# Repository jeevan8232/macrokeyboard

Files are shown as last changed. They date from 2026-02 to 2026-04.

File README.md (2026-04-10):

# macrokeyboard
macro keyboard and space mouse using rpi pico. circuitpython code

https://www.thingiverse.com/thing:7293580

https://www.youtube.com/watch?v=AjmmTDKetks

# Hand-Wiring the Electronics

Since we are keeping this accessible, there is no custom PCB required—everything is hand-wired directly to the microcontroller!

Hand-wiring a project like this is incredibly rewarding. Take your time, trim your wires to length so they fit nicely inside the shell, and double-check your connections as you go.

Below is the complete wiring guide based on the Raspberry Pi Pico (RP2040) pinout used for this project.

1. Power Distribution (ALL components VCC (+) and GND (-))
First, let's establish our power and ground lines. It helps to daisy-chain your ground wires or create a small ground hub.

VBUS (Pin 40, 5V from USB): Connect your LED Strip VCC here.
3V3 (Pin 36, 3.3V Out): Connect the Joystick VCC, Magnetometer VCC, and Rotary Encoder VCCs here.
GND (Any Ground Pin): Connect the GND from all components (LEDs, Joystick, Magnetometer, Encoders, Extra Switches, etc.) to the microcontroller's ground.
2. The Key Matrix (Macro Keyboard)
To save pins, the mechanical switches are wired in a 5x5 matrix. You will need to solder diodes to your switches to prevent "ghosting" when pressing multiple keys.

🚨 CRITICAL DIODE NOTE: When soldering the 1N4148 diodes to the mechanical switches, the black line on the diode must face AWAY from the switch pin, Check the image.

* Rows (Solder to the diode tails):

Row 1 ➔ GP0
Row 2 ➔ GP1
Row 3 ➔ GP2
Row 4 ➔ GP3
Row 5 ➔ GP4
Columns (Solder to the other switch pin): (Note: These are wired in reverse order in the code! Don't worry we can always change the pin numbers in the code)
Col 1 ➔ GP9
Col 2 ➔ GP8
Col 3 ➔ GP7
Col 4 ➔ GP6
Col 5 ➔ GP5
3. The Space Mouse (Magnetometer & Joystick)
This is the core of our 3D navigation!

Magnetometer (MLX90393): This communicates via I2C. Ensure your breakout board is in I2C mode.
SDA ➔ GP16
SCL ➔ GP17

Analog Joystick Module:
VRx (X-Axis) ➔ GP27
VRy (Y-Axis) ➔ GP26
SW (Button) ➔ GP22

4. Rotary Encoders & Extra Buttons
These give you scroll and quick-action control.

Encoder 1 (Left - Horizontal Scroll / Right Click):
CLK ➔ GP10
DT ➔ GP11
SW ➔ GP12
Encoder 2 (Right - Vertical Scroll / Home):
CLK ➔ GP13
DT ➔ GP14
SW ➔ GP15
Extra Button 1 (F6 - Fit View): Wire one leg to GP18, the other to GND.
Extra Button 2 (Mode/Color Cycle): Wire one leg to GP19, the other to GND.
5. RGB Lighting
To give the macro pad that premium glow:

WS2812B Data In (DIN): ➔ GP28

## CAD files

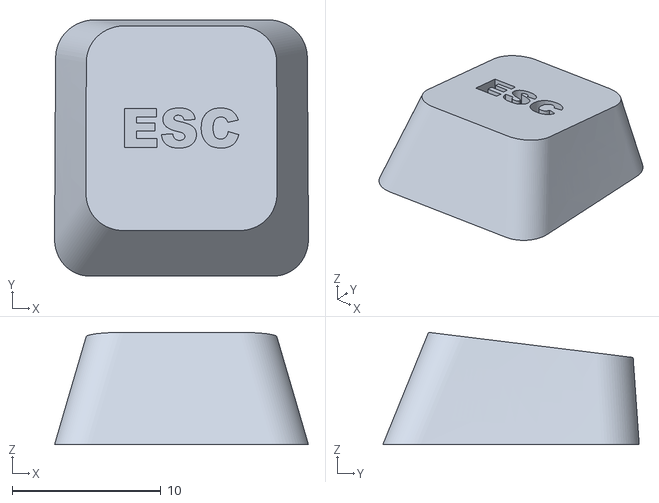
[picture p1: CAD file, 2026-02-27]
3d files/stl/MX Keycap check tolerance by printing one upside down no support /MX Keycap ESC.stl
17.1 x 17.2 x 7.55

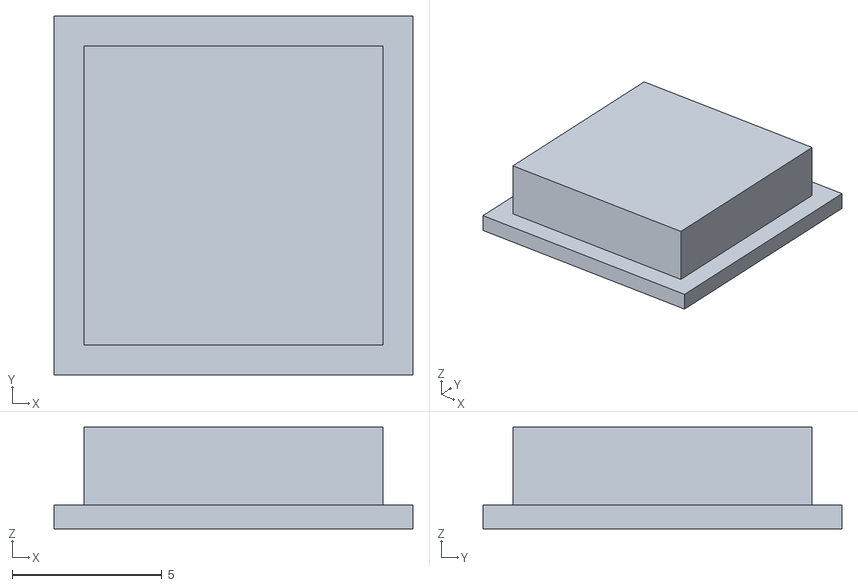
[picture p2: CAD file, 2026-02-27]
3d files/stl/switch x 2 copies.stl
12.0 x 12.0 x 3.40

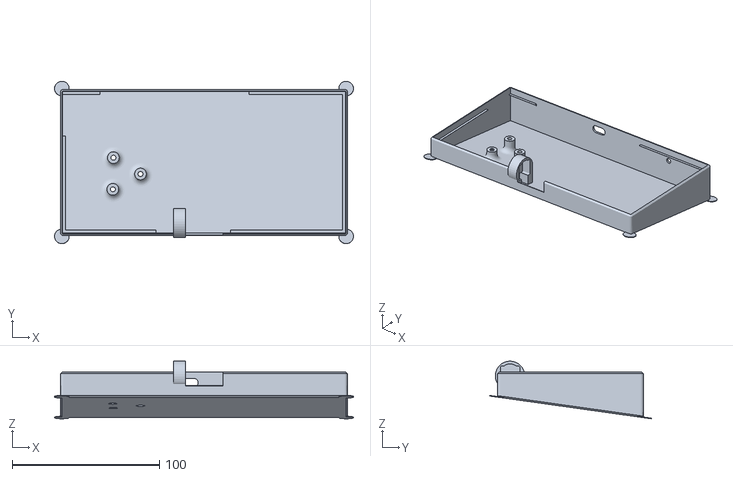
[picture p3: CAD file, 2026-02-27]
3d files/stl/Base with support tree.stl
203.0 x 110.3 x 39.1

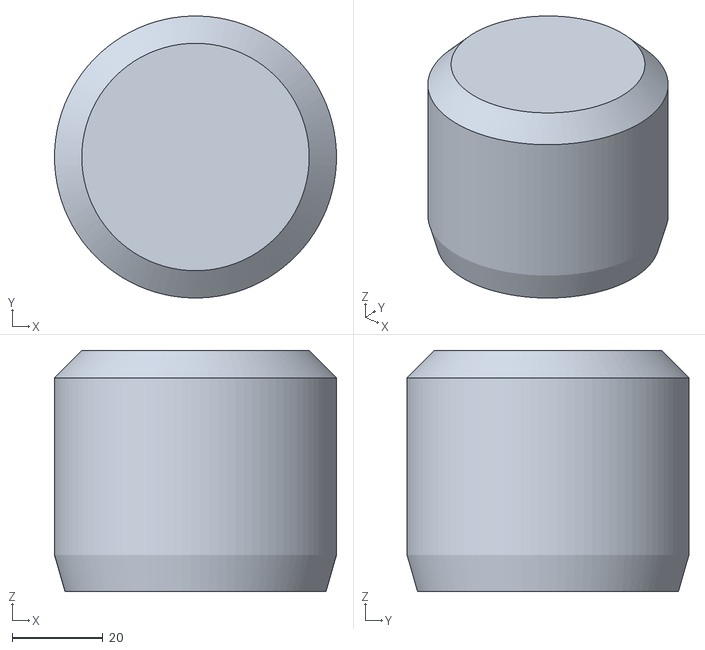
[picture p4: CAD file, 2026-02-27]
3d files/stl/Spacemouse Knob.stl
62.0 x 62.0 x 53.0

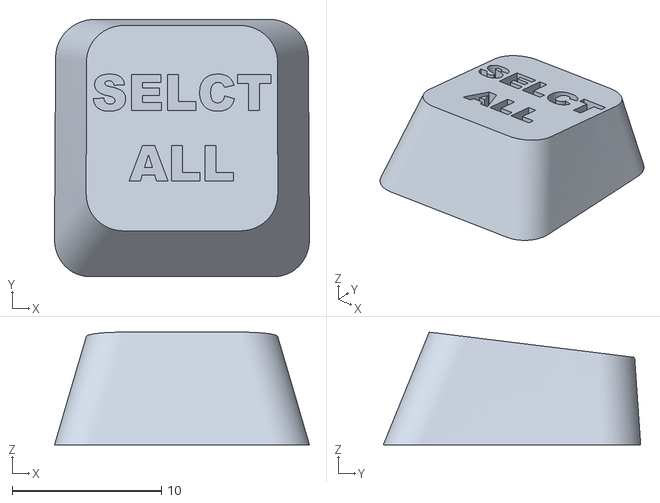
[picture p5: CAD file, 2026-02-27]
3d files/stl/MX Keycap check tolerance by printing one upside down no support /MX Keycap Select All.stl
17.1 x 17.2 x 7.55

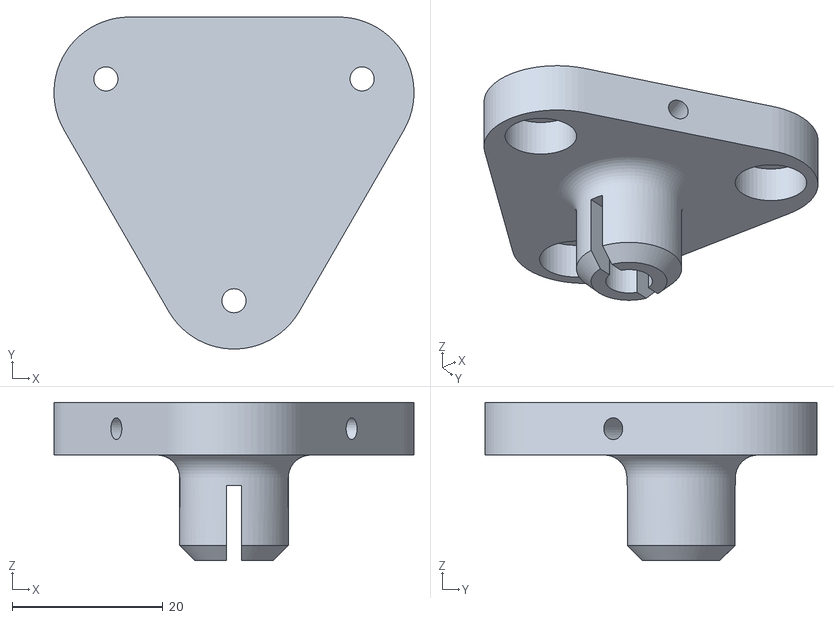
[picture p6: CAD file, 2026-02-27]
3d files/stl/Spacemouse Top Magnet Holder.stl
47.7 x 44.0 x 21.0

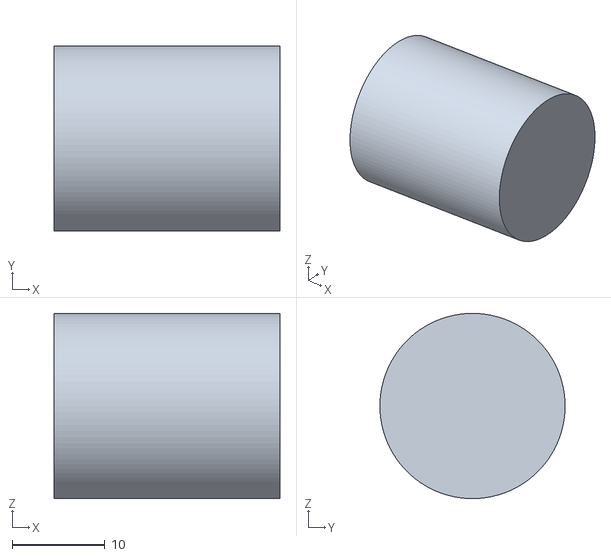
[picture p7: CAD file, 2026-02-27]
3d files/stl/Encoder knob vertical scroll.stl
24.4 x 20.0 x 20.0

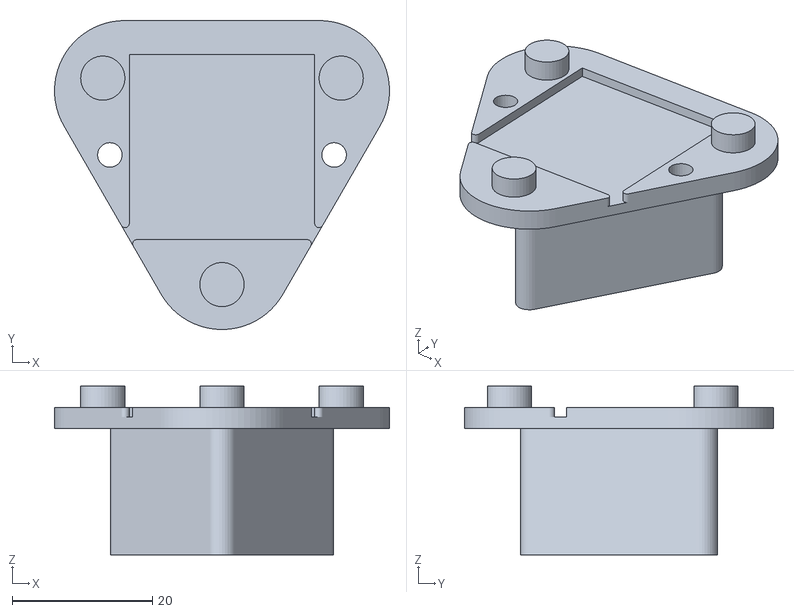
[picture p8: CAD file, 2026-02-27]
3d files/stl/Spacemouse base.stl
47.7 x 44.0 x 24.0

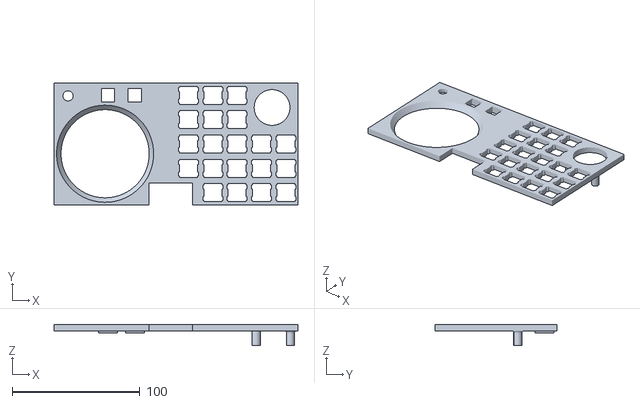
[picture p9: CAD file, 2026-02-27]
3d files/stl/Top.stl
191.0 x 95.2 x 16.6

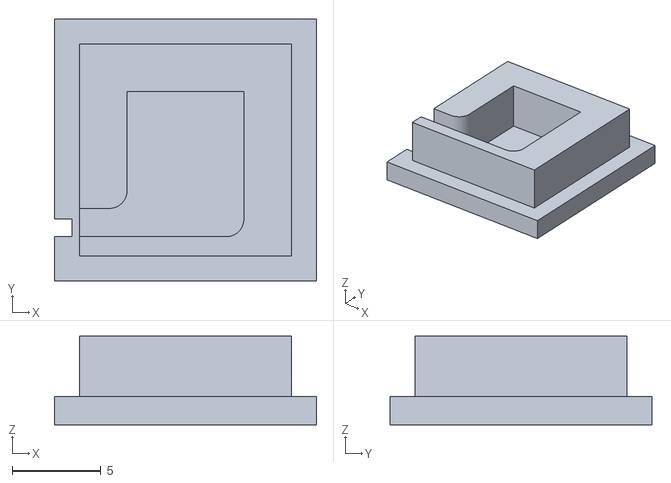
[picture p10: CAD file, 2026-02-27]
3d files/stl/switch base x 2 copies.stl
14.8 x 14.8 x 5.00

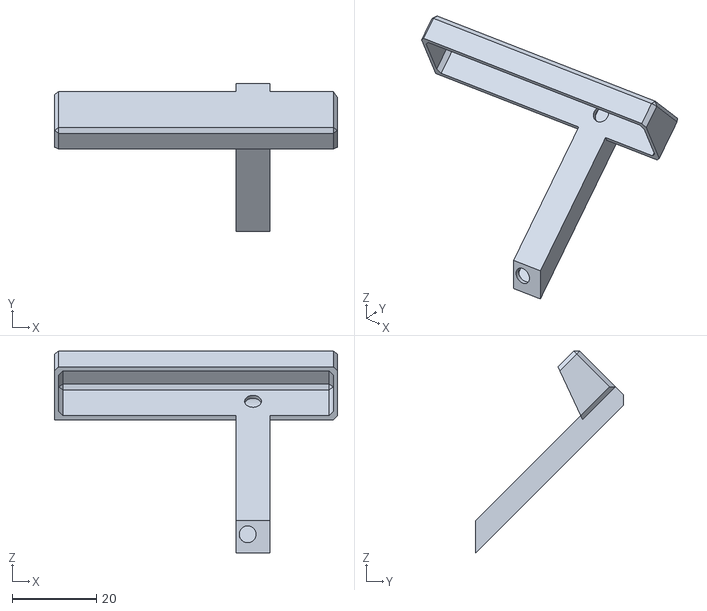
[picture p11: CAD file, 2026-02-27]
3d files/stl/Ledstrip case.stl
67.0 x 34.9 x 47.8

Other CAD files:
3d files/stl/MX Keycap check tolerance by printing one upside down no support /MX Keycap Find.stl
3d files/stl/MX Keycap check tolerance by printing one upside down no support /MX Keycap Paste.stl
3d files/stl/MX Keycap check tolerance by printing one upside down no support /MX Keycap Home.stl
3d files/stl/MX Keycap check tolerance by printing one upside down no support /MX Keycap Extrude.stl
3d files/stl/MX Keycap check tolerance by printing one upside down no support /Arrow Up.stl
3d files/stl/MX Keycap check tolerance by printing one upside down no support /Arrow Down.stl
3d files/stl/MX Keycap check tolerance by printing one upside down no support /MX Keycap Switch Window.stl
3d files/stl/Encoder knob horizontal scroll.stl
3d files/stl/Ledstrip cover.stl
3d files/stl/MX Keycap check tolerance by printing one upside down no support /Arrow Left.stl
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

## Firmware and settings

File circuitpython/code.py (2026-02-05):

import time
import board
import digitalio
import usb_hid
import rotaryio
import keypad
import analogio
import neopixel
import busio
from adafruit_hid.keyboard import Keyboard
from adafruit_hid.keycode import Keycode
from adafruit_hid.consumer_control import ConsumerControl
from adafruit_hid.consumer_control_code import ConsumerControlCode
from adafruit_hid.mouse import Mouse

# --- 1. CONFIGURATION ---

COMMAND = Keycode.GUI 

# Key Matrix Pins
ROW_PINS = (board.GP0, board.GP1, board.GP2, board.GP3, board.GP4)
COL_PINS = (board.GP9, board.GP8, board.GP7, board.GP6, board.GP5)

# Encoder Pins
ENC1_CLK, ENC1_DT, ENC1_SW = board.GP10, board.GP11, board.GP12
ENC2_CLK, ENC2_DT, ENC2_SW = board.GP13, board.GP14, board.GP15

# Joystick & Extra Buttons
JOY_X_PIN = board.GP27
JOY_Y_PIN = board.GP26
JOY_SW_PIN = board.GP22
BTN_EXTRA1_PIN = board.GP18
BTN_EXTRA2_PIN = board.GP19

# I2C (Space Mouse) & LED
I2C_SDA, I2C_SCL = board.GP16, board.GP17
LED_PIN = board.GP28
NUM_LEDS = 4

# SCROLL SETTINGS
SCROLL_SPEED = 20  # Set to 1 for default, 2 or 3 for faster scrolling

# LED COLOR CYCLE SETTINGS
# 4 Colors + OFF at the end
LED_COLORS = [
    (255, 100, 0),   # 1. Cyan
    (0, 0, 255),   # 2. Magenta
    (255, 255, 0),   # 3. Yellow
    (255, 255, 255), # 4. White
    (0, 0, 0)        # 5. OFF
]

# SPACE MOUSE SETTINGS (Fusion 360)
SM_DEADZONE = 100.0      
SM_SENSITIVITY = 15.0   
SM_Z_THRESHOLD = 100.0   

# --- 2. SETUP OBJECTS ---

kbd = Keyboard(usb_hid.devices)
cc = ConsumerControl(usb_hid.devices)
mouse = Mouse(usb_hid.devices)

# LED Setup
pixels = neopixel.NeoPixel(LED_PIN, NUM_LEDS, brightness=1.0)
pixels.fill((255, 255, 0)) # Startup Orange (Not in cycle, just for boot)

# Matrix Setup
keys = keypad.KeyMatrix(ROW_PINS, COL_PINS, columns_to_anodes=True)

# Direct Keys
# Index 0: Extra1, Index 1: Extra2, Index 2: Joystick Btn
direct_keys = keypad.Keys(
    (BTN_EXTRA1_PIN, BTN_EXTRA2_PIN, JOY_SW_PIN),
    value_when_pressed=False,
    pull=True
)

# Encoders
encoder1 = rotaryio.IncrementalEncoder(ENC1_CLK, ENC1_DT)
last_position1 = 0
encoder2 = rotaryio.IncrementalEncoder(ENC2_CLK, ENC2_DT)
last_position2 = 0

# Encoder Switches
encoder_switches = keypad.Keys(
    (ENC1_SW, ENC2_SW),
    value_when_pressed=False,
    pull=True
)

# Joystick Analog
joy_x = analogio.AnalogIn(JOY_X_PIN)
joy_y = analogio.AnalogIn(JOY_Y_PIN)

# Magnetometer Setup & Calibration
mlx = None
mlx_offsets = [0, 0, 0] 

try:
    import adafruit_mlx90393
    i2c = busio.I2C(I2C_SCL, I2C_SDA, frequency=400_000)
    mlx = adafruit_mlx90393.MLX90393(i2c)
    mlx.gain = adafruit_mlx90393.GAIN_1X 
    print("MLX90393 Found! Calibrating...")
    
    # Calibration Routine
    x_sum, y_sum, z_sum = 0, 0, 0
    for _ in range(20):
        mx, my, mz = mlx.magnetic
        x_sum += mx
        y_sum += my
        z_sum += mz
        time.sleep(0.01)
    
    mlx_offsets = [x_sum/20, y_sum/20, z_sum/20]
    print("Calibration Done:", mlx_offsets)
    pixels.fill((0, 255, 0)) # Green = Ready
    time.sleep(0.2)
    pixels.fill(LED_COLORS[0]) # Set to first color in cycle

except Exception as e:
    print("MLX90393 Init Failed:", e)
    pixels.fill((255, 0, 0)) # Red = Error

# --- 3. KEY MAPPING ---

KEYMAP = [
    [(COMMAND, Keycode.C), (COMMAND, Keycode.V), (COMMAND, Keycode.A), None, None],
    [(COMMAND, Keycode.ALT, Keycode.V), (COMMAND, Keycode.F), Keycode.ESCAPE, None, None],
    [Keycode.HOME, Keycode.E, (COMMAND, Keycode.Z), Keycode.SPACEBAR, Keycode.L],
    [Keycode.SHIFT, Keycode.COMMAND, Keycode.UP_ARROW, Keycode.TAB, Keycode.RIGHT_CONTROL],
    [None, Keycode.LEFT_ARROW, Keycode.DOWN_ARROW, Keycode.RIGHT_ARROW, (COMMAND, Keycode.S)]
]

# --- 4. HELPER FUNCTIONS ---

def read_joystick(pin_obj):
    val = pin_obj.value
    if abs(val - 32768) < 2000:
        return 0
    return int((val - 32768) / 1000)

def handle_keypress(key_item, pressed):
    if pressed:
        if isinstance(key_item, tuple):
            kbd.press(*key_item)
        else:
            kbd.press(key_item)
    else:
        if isinstance(key_item, tuple):
            kbd.release(*key_item)
        else:
            kbd.release(key_item)

# --- 5. MAIN LOOP ---

print("Ready")

last_sensor_read = 0
sensor_interval = 0.02

# State Variables
is_orbiting = False
led_index = 0 # Tracks current color in cycle

while True:
    now = time.monotonic()

    # A. HANDLE MATRIX
    event = keys.events.get()
    if event:
        row, col = event.key_number // 5, event.key_number % 5
        key_code = KEYMAP[row][col]
        if key_code:
            handle_keypress(key_code, event.pressed)

    # B. HANDLE DIRECT KEYS
    direct_event = direct_keys.events.get()
    if direct_event and direct_event.pressed:
        
        if direct_event.key_number == 0:   # Extra Btn 1 -> F6
            kbd.send(Keycode.F6)
            
        elif direct_event.key_number == 1: # Extra Btn 2 -> CYCLE LED COLORS
            # Increment index, wrap around if at end
            led_index = (led_index + 1) % len(LED_COLORS)
            pixels.fill(LED_COLORS[led_index])
            
        elif direct_event.key_number == 2: # Joystick Btn -> Click
            mouse.click(Mouse.LEFT_BUTTON)

    # C. HANDLE ENCODER SWITCHES
    enc_sw_event = encoder_switches.events.get()
    if enc_sw_event and enc_sw_event.pressed:
        if enc_sw_event.key_number == 0:   # Encoder 1 Switch -> Right Click
            mouse.click(Mouse.RIGHT_BUTTON)
        elif enc_sw_event.key_number == 1: # Encoder 2 Switch -> Home Key
            kbd.send(Keycode.HOME)
    
    # D. HANDLE ENCODERS
    
    # Encoder 1: HORIZONTAL SCROLL
    current_position1 = encoder1.position
    delta1 = current_position1 - last_position1
    
    if delta1 != 0:
        kbd.press(Keycode.SHIFT)
        # Use delta * SCROLL_SPEED to handle fast spins and multiplier
        mouse.move(wheel=delta1 * SCROLL_SPEED)
        kbd.release(Keycode.SHIFT)
        last_position1 = current_position1

    # Encoder 2: VERTICAL SCROLL
    current_position2 = encoder2.position
    delta2 = current_position2 - last_position2
    
    if delta2 != 0:
        # We invert delta2 because your original logic had 'current > last' (positive)
        # resulting in 'wheel=-1' (negative).
        mouse.move(wheel=-delta2 * SCROLL_SPEED)
        last_position2 = current_position2

    # E. HANDLE SENSORS
    if now - last_sensor_read > sensor_interval:
        
        # 1. Joystick
        jx = read_joystick(joy_x)
        jy = read_joystick(joy_y)
        if jx != 0 or jy != 0:
            mouse.move(x=jx, y=jy)

        # 2. Space Mouse
        if mlx:
            try:
                raw_x, raw_y, raw_z = mlx.magnetic
                
                dx = raw_x - mlx_offsets[0]
                dy = raw_y - mlx_offsets[1]
                dz = raw_z - mlx_offsets[2]
                
                # Orbit Logic
                if abs(dx) > SM_DEADZONE or abs(dy) > SM_DEADZONE:
                    if not is_orbiting:
                        kbd.press(Keycode.SHIFT)
                        mouse.press(Mouse.MIDDLE_BUTTON)
                        is_orbiting = True
                    
                    move_x = int(dx / SM_SENSITIVITY)
                    move_y = int(dy / SM_SENSITIVITY) * -1 
                    
                    move_x = max(-127, min(127, move_x))
                    move_y = max(-127, min(127, move_y))
                    
                    mouse.move(x=move_x, y=move_y)
                else:
                    if is_orbiting:
                        mouse.release(Mouse.MIDDLE_BUTTON)
                        kbd.release(Keycode.SHIFT)
                        is_orbiting = False

                # Zoom Logic
                if not is_orbiting and abs(dz) > SM_Z_THRESHOLD:
                    if dz > 0:
                        mouse.move(wheel=1)
                    else:
                        mouse.move(wheel=-1)

            except Exception:
                pass 
        
        last_sensor_read = now

    time.sleep(0.001)

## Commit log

2026-02-05 Added lib files. use the files according to your circuitpython version. current version is CircuitPython 10.0.3
2026-02-05 consolidated wiring list based on final code
2026-02-27 STL files for 3D printing
    [Arrow Down.stl, Arrow Left.stl, Arrow Right.stl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]
